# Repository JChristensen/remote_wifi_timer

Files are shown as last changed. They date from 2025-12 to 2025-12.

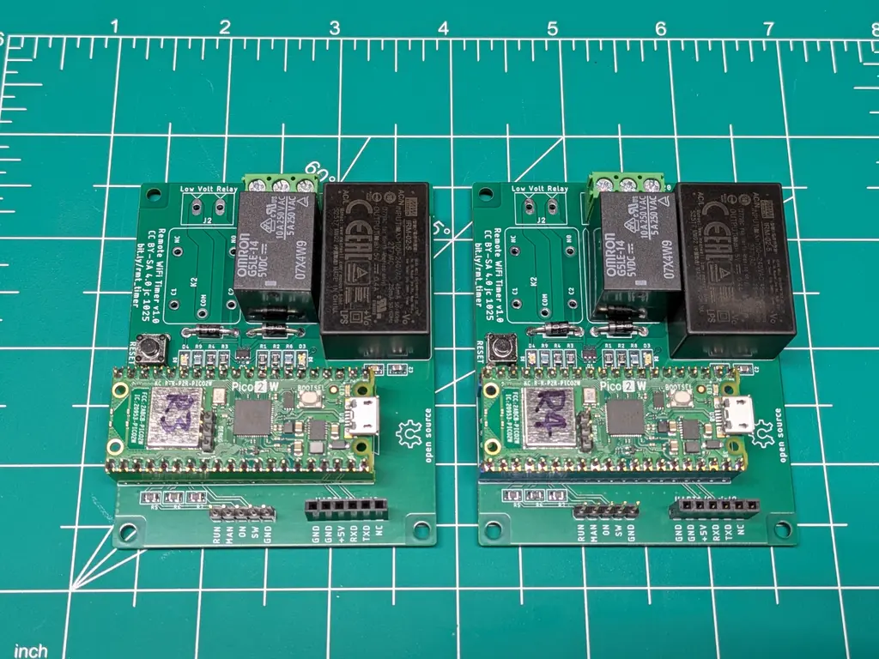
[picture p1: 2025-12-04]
extras/boards.webp

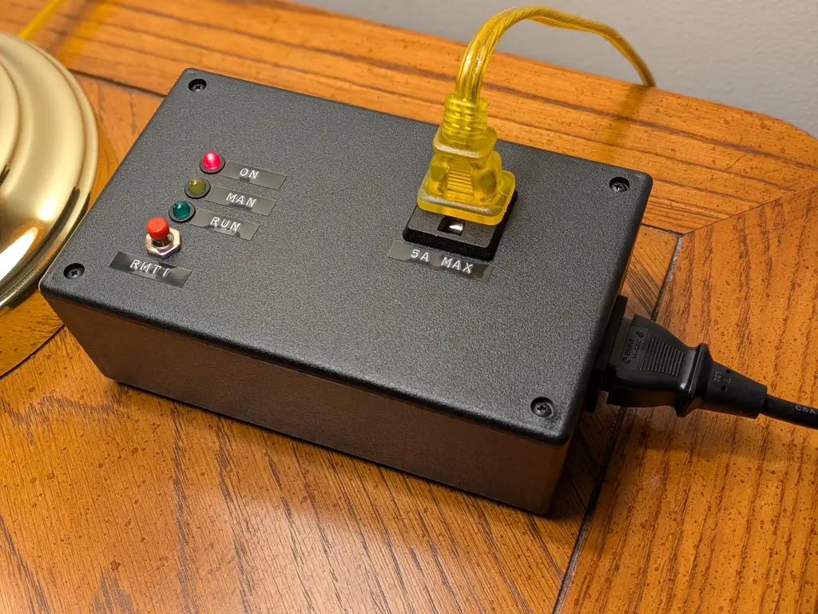
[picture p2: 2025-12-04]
extras/box.webp

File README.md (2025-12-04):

# Remote WiFi Timer  
https://github.com/JChristensen/remote_wifi_timer  
README file  
Jack Christensen  
Oct-2025

## License
  
This work is licensed under the [Creative Commons Attribution-ShareAlike 4.0 International License](https://creativecommons.org/licenses/by-sa/4.0/).

## See also
[Main control program.](https://github.com/JChristensen/timer_main)  
[Microcontroller firmware.](https://github.com/JChristensen/timer_remote)  
[A small PCB for the LEDs and pushbutton.](https://github.com/JChristensen/ac-timer-panel)

## Overview
This is the printed circuit board for the remote timer units. For an overall description of the project, see [the main control program repo](https://github.com/JChristensen/timer_main).

A Bill of Materials is available in this repo and also [on Mouser.com](https://www.mouser.com/Tools/Project/Share?AccessID=4ef4109354).

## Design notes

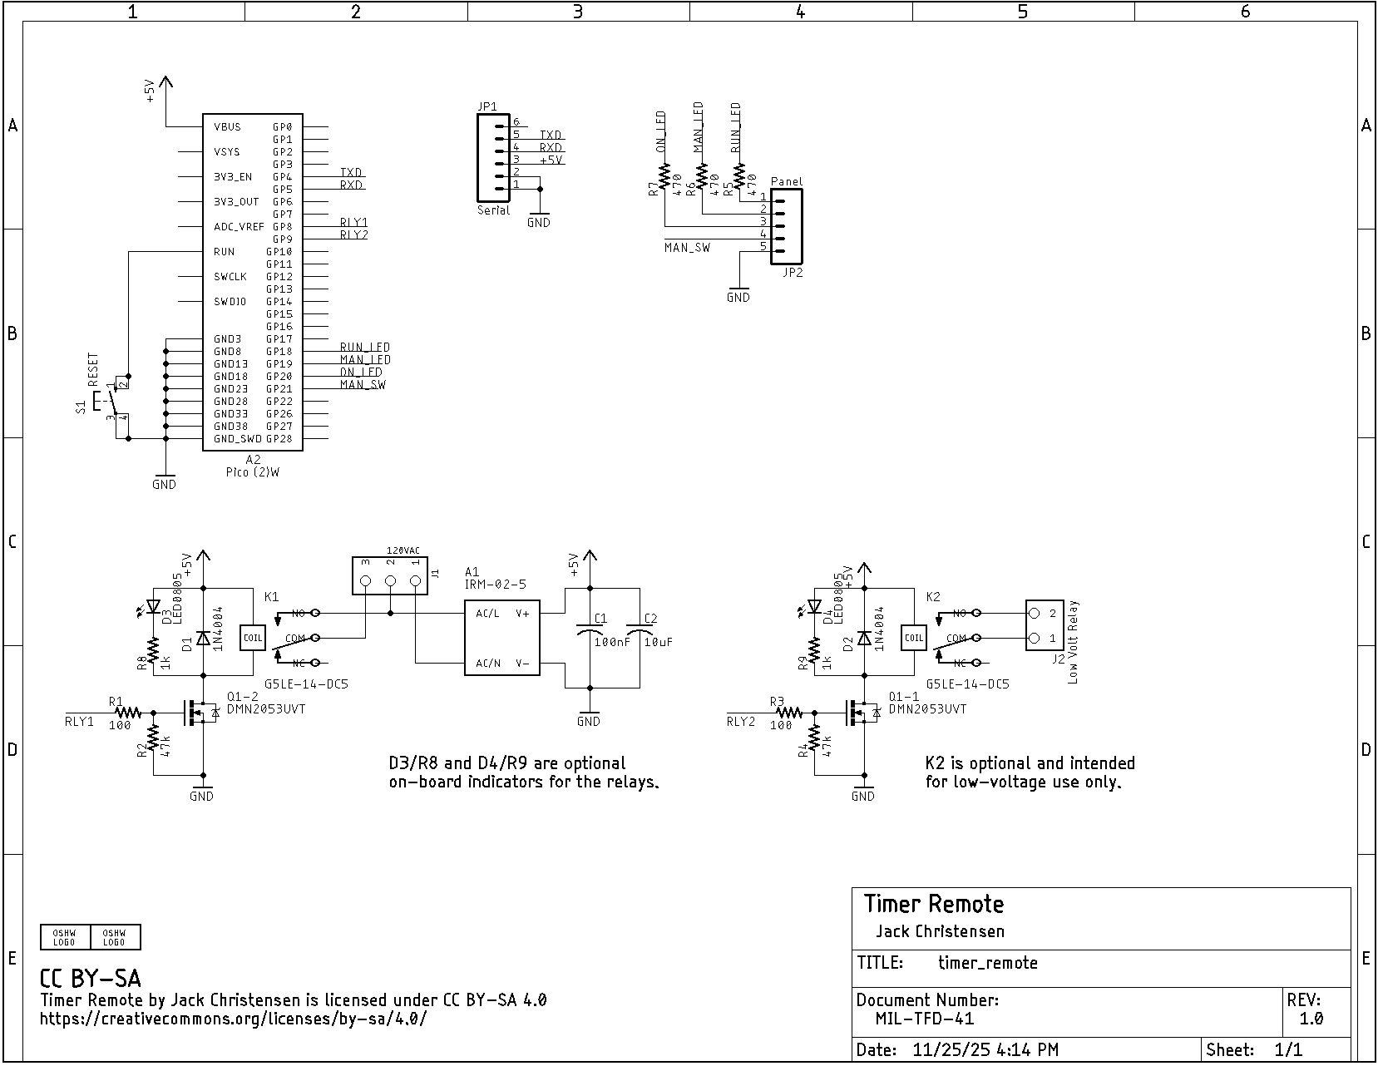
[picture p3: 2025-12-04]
schematic.png

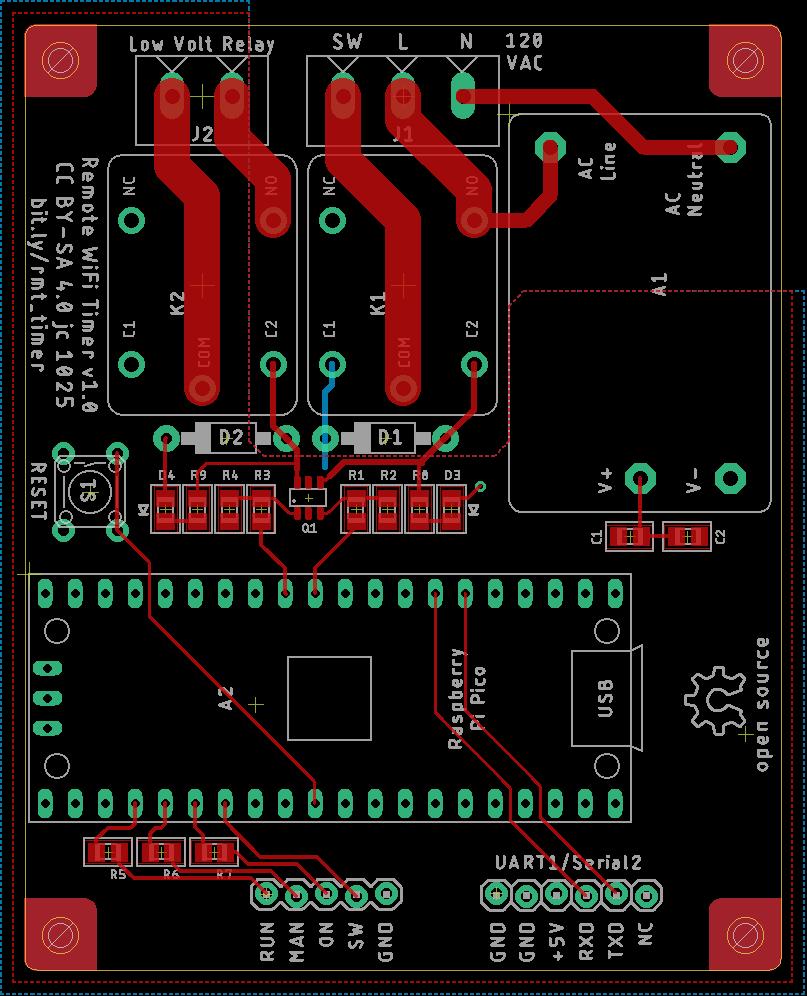
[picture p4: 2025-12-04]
board.png

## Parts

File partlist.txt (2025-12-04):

Partlist

Exported from timer_remote.sch at 11/28/25 7:55 AM

EAGLE Version 9.6.2 Copyright (c) 1988-2020 Autodesk, Inc.

Assembly variant: 

Part     Value          Device             Package       Library  Sheet

A1       IRM-02-5       IRM-01             IRM-01        _jc      1
A2       Pico (2)W      PICOPICO           PICO          _jc      1
C1       100nF          C-USM0805          M0805         _jc      1
C2       10uF           C-USM0805          M0805         _jc      1
D1       1N4004         DIODE1N400X        1N400X        _jc      1
D2       1N4004         DIODE1N400X        1N400X        _jc      1
D3       LED0805        LEDD0805A          D0805A        _jc      1
D4       LED0805        LEDD0805           D0805         _jc      1
J1       120VAC         OST-TB-35.08MM     OST-TB-3-0.20 _jc      1
J2       Low Volt Relay OST-TB-20.20IN     OST-TB-2-0.20 _jc      1
JP1      Serial         M06LOCK            1X06_LOCK     SparkFun 1
JP2      Panel          M05LOCK            1X05_LOCK     SparkFun 1
K1       G5LE-14-DC5    RELAY-SPDT         NAIS-JS1-5V   _jc      1
K2       G5LE-14-DC5    RELAY-SPDT         NAIS-JS1-5V   _jc      1
Q1       DMN2053UVT     DUAL-MOSFETSOT23-6 SOT23-6       _jc      1
R1       100            R-US_M0805         M0805         _jc      1
R2       47k            R-US_M0805         M0805         _jc      1
R3       100            R-US_M0805         M0805         _jc      1
R4       47k            R-US_M0805         M0805         _jc      1
R5       470            R-US_M0805         M0805         _jc      1
R6       470            R-US_M0805         M0805         _jc      1
R7       470            R-US_M0805         M0805         _jc      1
R8       1k             R-US_M0805         M0805         _jc      1
R9       1k             R-US_M0805         M0805         _jc      1
S1       RESET          10-XXOCT           B3F-10XXOCT   _jc      1

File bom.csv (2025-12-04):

Remote WiFi Timer
https://github.com/JChristensen/remote_wifi_timer
Bill of Materials
Part | Qty | Value | Description | Manufacturer | Mfr_Part_ Nbr | Mouser_Part_Nbr | Notes
A1 | 1 | IRM-02-5 | Power Supply, 2W 5V 400mA | Mean Well | IRM-02-5 | 709-IRM02-5
A2 | 1 | Pico (2)W | Pico2W microcontroller | Raspberry Pi | SC1633 | 358-SC1633 | Or PicoW.
C1 | 1 | 100nF | MLCC 50V 0.1uF X5R or X7R 0805 | KAM21BR71H104JT | 581-KAM21BR71H104JT | 581-KAF21BR71H104JM | Or equivalent.
C2 | 1 | 10uF | MLCC 6.3V 10uF X5R or X7R 0805 | KYOCERA AVX | KGM21AR50J106KU | 581-KGM21AR50J106KU | Or equivalent.
D1, D2 | 2 | 1N4004 | 1A 400V Standard rectifier | On Semi | 1N4004RLG | 863-1N4004RLG | Or equivalent. D2 optional if K2 not installed.
D3, D4 | 3 | LTST-C171YKT | SMT LED, 0805 | LITEON | LTST-C171YKT | 859-LTST-C171YKT | Or equivalent. Optional onboard indicators.
J1 | 1 | 1935174 | 5mm Terminal Block, 3 Position | Phoenix Contact | 1935174 | 651-1935174
J2 | 1 | 1935161 | 5mm Terminal Block, 2 Position | Phoenix Contact | 1935161 | 651-1935161
K1, K2 | 2 |  | Power Relay SPDT Sealed 5VDC | Omron | G5LE-14-DC5 | 653-G5LE-14-DC5 | K2 is optional.
Q1 | 1 | DMN2053UVT-7 | Dual MOSFET | Diodes Incorporated | DMN2053UVT-7 | 621-DMN2053UVT-7
R1, R3 | 2 | 100Ω | Thick film resistor, 0805, 0.25W, 1% | KOA Speer | RK73H2ATTD1000F | 660-RK73H2ATTD1000F | Or equivalent. R3 optional if K2 not installed.
R2, R4 | 2 | 47kΩ | Thick film resistor, 0805, 0.25W, 1% | KOA Speer | RK73H2ATTD4702F | 660-RK73H2ATTD4702F | Or equivalent.
R5, R6, R7 | 3 | 470Ω | Thick film resistor, 0805, 0.25W, 1% | KOA Speer | RK73H2ATTD4700F | 660-RK73H2ATTD4700F | Or equivalent.
R8, R9 | 2 | 1kΩ | Thick film resistor, 0805, 0.25W, 1% | KOA Speer | RK73H2ATTD1001F | 660-RK73H2ATTD1001F | Or equivalent. Optional if D3, D4 not installed.
S1 | 1 |  | Tactile button switch | Omron | B3F-1022 | 653-B3F-1022 | Or equivalent.

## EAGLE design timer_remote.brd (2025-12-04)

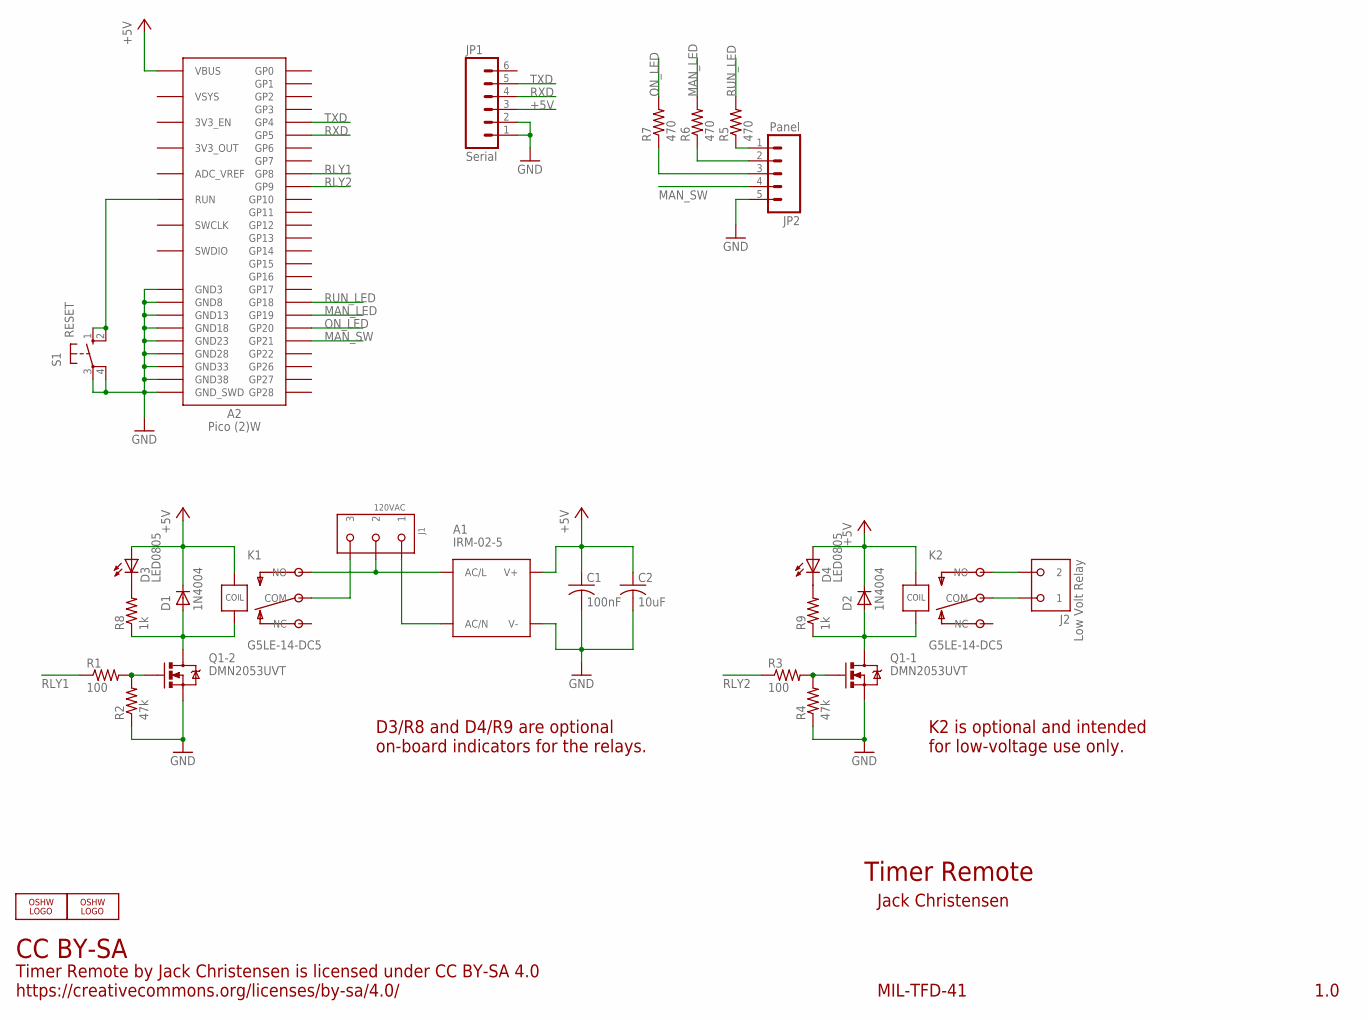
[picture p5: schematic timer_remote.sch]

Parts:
A1: IRM-02-5; IRM-01
A2: Pico (2)W; PICO
C1: 100nF; M0805
C2: 10uF; M0805
D1, D2: 1N4004; 1N400X
D3: LED0805; D0805A
D4: LED0805; D0805
J1: 120VAC; OST-TB-3-0.20
J2: Low Volt Relay; OST-TB-2-0.20
JP1: Serial; 1X06_LOCK
JP2: Panel; 1X05_LOCK
K1, K2: G5LE-14-DC5; NAIS-JS1-5V
LOGO1, LOGO2: OSHW_LOGO_10MILX0200-NT; OSHW_10X200_NOTEXT
Q1: DMN2053UVT; SOT23-6
R1, R3: 100; M0805
R2, R4: 47k; M0805
R5, R6, R7: 470; M0805
R8, R9: 1k; M0805
S1: RESET; B3F-10XXOCT

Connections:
+5V: A1.V+, A2.P$40 (VBUS), C1.1, C2.1, D1.K, D2.K, D3.A, D4.A, JP1.3, K1.C1, K2.C1
GND: A1.V-, A2.P$03 (GND3), A2.P$08 (GND8), A2.P$13 (GND13), A2.P$18 (GND18), A2.P$23 (GND23), A2.P$28 (GND28), A2.P$33 (GND33), A2.P$38 (GND38), A2.P$SWGND (GND_SWD), C1.2, C2.2, JP1.1, JP1.2, JP2.5, Q1.2 (S), Q1.5 (S), R2.1, R4.1, S1.3, S1.4 (P1)
MAN_LED: A2.P$25 (GP19), R6.2
MAN_SW: A2.P$27 (GP21), JP2.4
unnamed: J2.P$2 (2), K2.NO
unnamed: J2.P$1 (1), K2.COM
unnamed: Q1.1 (G), R3.2, R4.2
unnamed: D2.A, K2.C2, Q1.6 (D), R9.1
unnamed: A2.P$30 (RUN), S1.1 (S), S1.2 (S1)
unnamed: D1.A, K1.C2, Q1.4 (D), R8.1
unnamed: A1.AC/L, J1.P$2 (2), K1.NO
unnamed: A1.AC/N, J1.P$1 (1)
unnamed: J1.P$3 (3), K1.COM
unnamed: Q1.3 (G), R1.2, R2.2
unnamed: JP2.1, R5.1
unnamed: D3.K (C), R8.2
unnamed: JP2.2, R6.1
unnamed: JP2.3, R7.1
unnamed: D4.K (C), R9.2
ON_LED: A2.P$26 (GP20), R7.2
RLY1: A2.P$11 (GP8), R1.1
RLY2: A2.P$12 (GP9), R3.1
RUN_LED: A2.P$24 (GP18), R5.2
RXD: A2.P$07 (GP5), JP1.4
TXD: A2.P$06 (GP4), JP1.5

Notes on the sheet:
Timer Remote
CC BY-SA
Jack Christensen
MIL-TFD-41
1.0
Timer Remote by Jack Christensen is licensed under CC BY-SA 4.0 https://creativecommons.org/licenses/by-sa/4.0/
D3/R8 and D4/R9 are optional on-board indicators for the relays.
K2 is optional and intended for low-voltage use only.

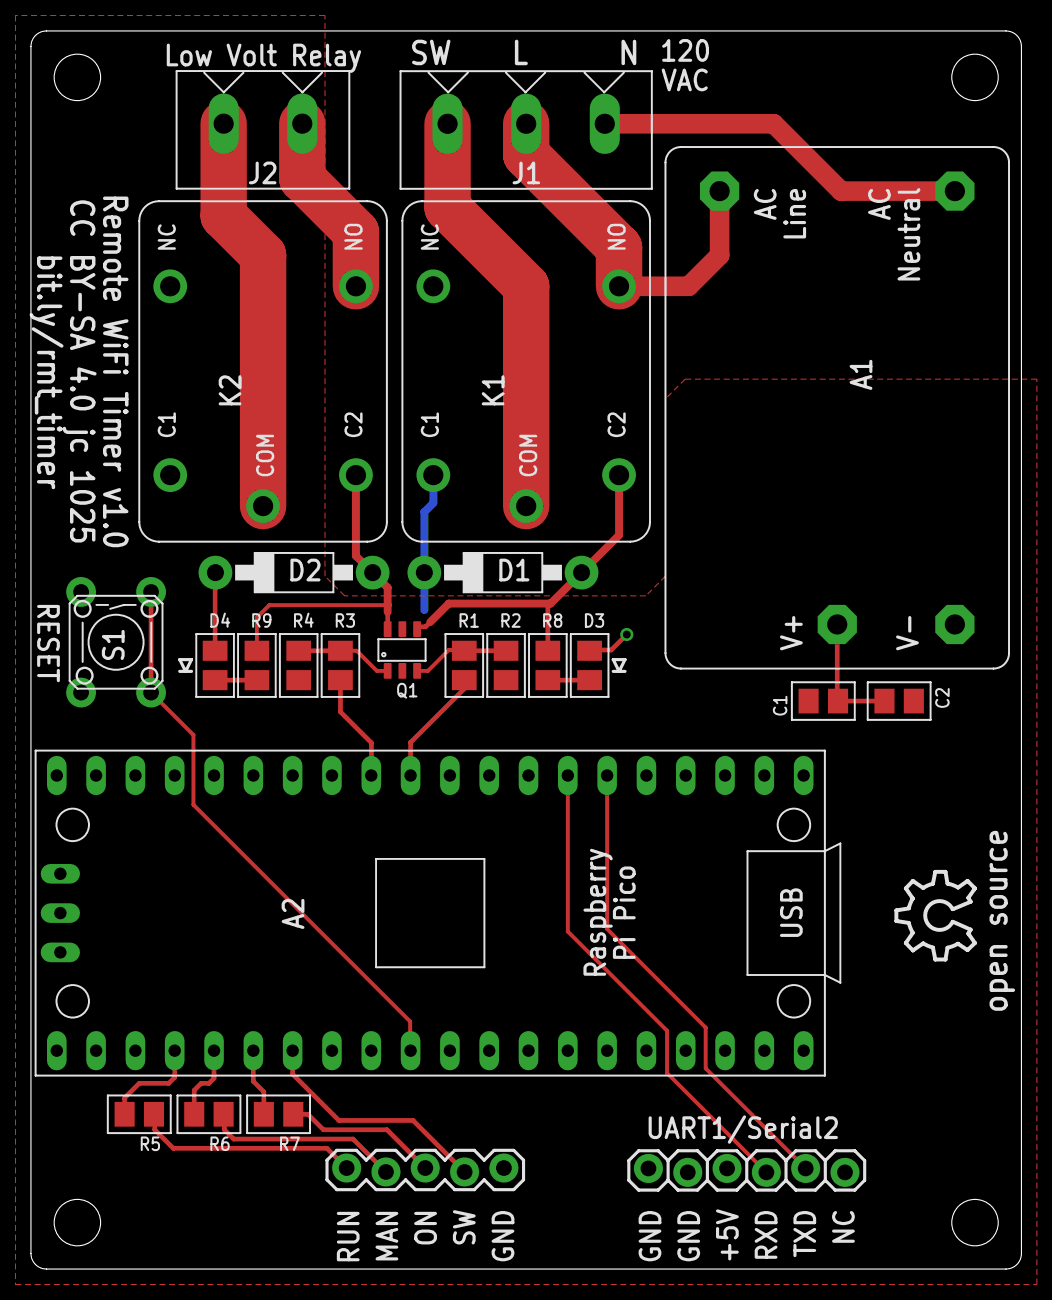
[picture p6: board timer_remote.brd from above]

Board: 2 copper layers, 64.0 x 80.0 mm, 27 parts (1 on the bottom side), 25 nets.

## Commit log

2025-10-04 Initial commit.
    [timer_remote.brd, timer_remote.sch]
2025-10-07 Sent to fab.
    [timer_remote.sch]
2025-12-04 Minor tweaks to PCB traces, update README, BoM, images.
    [bom.csv, bom.ods, timer_remote.brd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]

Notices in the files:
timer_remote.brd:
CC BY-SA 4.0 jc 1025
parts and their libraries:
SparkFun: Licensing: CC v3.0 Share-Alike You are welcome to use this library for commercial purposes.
